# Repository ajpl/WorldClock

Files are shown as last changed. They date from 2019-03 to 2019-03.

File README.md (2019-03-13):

# WorldClock

This is a WorldClock implementation using Atmega 328 and DS1307 as a RTC.

## Inspiration

This project was inspired by [this](https://www.instructables.com/id/The-Wordclock-Grew-Up/) instructable that relies on a DS1302 instead of a DS1307. A couple of changes had to be made since these clocks work in different ways ([DS1302 Datasheet](https://datasheets.maximintegrated.com/en/ds/DS1302.pdf) and [DS1307 Datasheet](https://datasheets.maximintegrated.com/en/ds/DS1307.pdf)).

## How To
- Get all the parts necessary according to the Bill of Materials in Part 8 of the instructable linked above (for electronics you may use the schematic if you prefer)
- Etch the PCB using your favorite method or using a service like [OSH Park](https://oshpark.com)

- Flash the program into your Atmega 328 using your programmer of choice

- Solder every component into your PCB

- Test it out

- Follow the instructions linked above in order to build the clock's enclosure

- Put everything together

- Enjoy!

## Dependencies

- [RTC Lib](https://github.com/adafruit/RTClib)

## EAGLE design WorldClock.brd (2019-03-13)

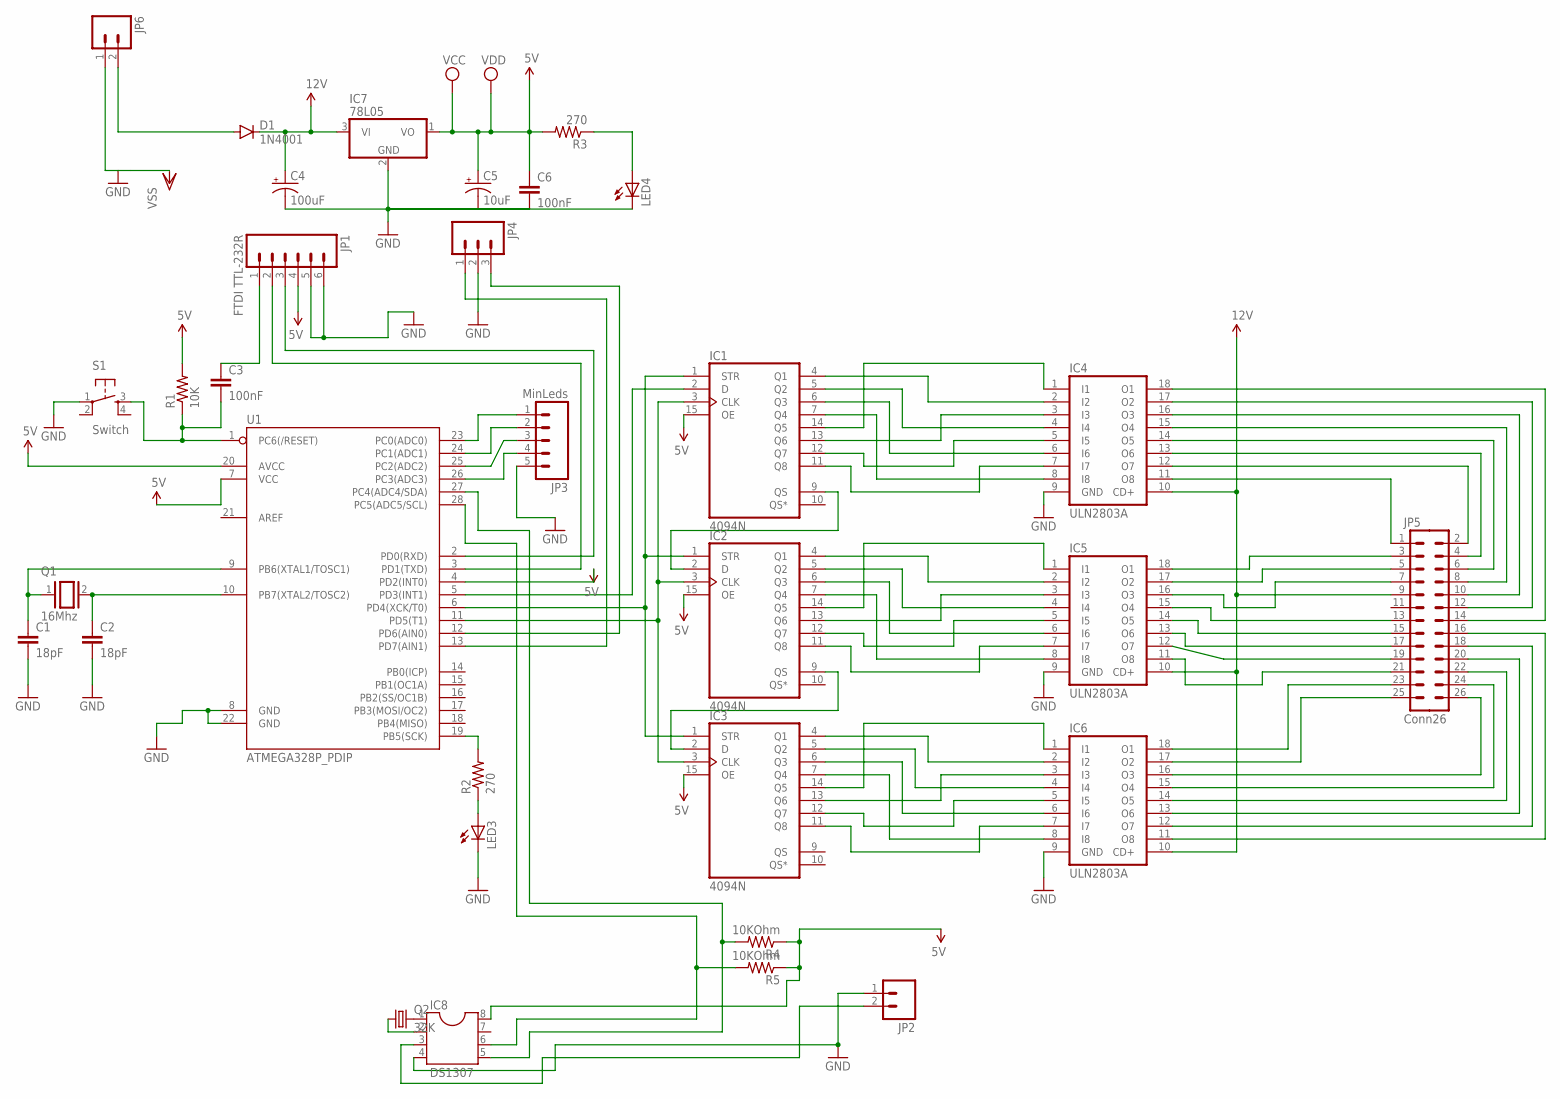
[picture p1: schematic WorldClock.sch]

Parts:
C1, C2: 18pF; CAP-PTH-SMALL2
C3, C6: 100nF; CAP-PTH-SMALL2
C4: 100uF; CPOL-RADIAL-100UF-25V
C5: 10uF; CPOL-RADIAL-10UF-25V
D1: 1N4001; DIODE-1N4148
IC1, IC2, IC3: 4094N; DIL16
IC4, IC5, IC6: ULN2803A; DIL18
IC7: 78L05; TO92
IC8: DS1307; SOCKET-08
JP1: FTDI TTL-232R; 1X06_NO_SILK
JP2, JP6: M025MM; SCREWTERMINAL-5MM-2
JP3: MinLeds; 1X05
JP4: M03-SCREW-5MM; SCREWTERMINAL-5MM-3
JP5: Conn26; 2X13
LED3, LED4: LED5MM
Q1: 16Mhz; QS
Q2: 32K; TC26V
R1: 10K; AXIAL-0.4
R2, R3: 270; AXIAL-0.4
R4, R5: 10KOhm; AXIAL-0.4
S1: Switch; TACTILE-PTH
U1: ATMEGA328P_PDIP; DIL28-3

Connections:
5V: C5.1 (+), C6.1, IC1.15 (OE), IC1.16 (VDD), IC2.15 (OE), IC2.16 (VDD), IC3.15 (OE), IC3.16 (VDD), IC7.1 (VO), IC8.8, JP1.4, R1.P$2 (2), R3.P$2 (2), R4.P$1 (1), R5.P$1 (1), U1.4 (PD2(INT0)), U1.7 (VCC), U1.20 (AVCC)
12V: C4.1 (+), D1.C, IC4.10 (CD+), IC5.10 (CD+), IC6.10 (CD+), IC7.3 (VI), JP5.9
GND: C1.2, C2.2, C4.2 (-), C5.2 (-), C6.2, IC1.8 (VSS), IC2.8 (VSS), IC3.8 (VSS), IC4.9 (GND), IC5.9 (GND), IC6.9 (GND), IC7.2 (GND), IC8.4, JP1.5, JP1.6, JP2.1, JP3.5, JP4.2, JP6.1, LED3.K (C), LED4.K (C), S1.1, U1.8 (GND), U1.22 (GND)
unnamed: C1.1, Q1.1, U1.9 (PB6(XTAL1/TOSC1))
unnamed: C2.1, Q1.2, U1.10 (PB7(XTAL2/TOSC2))
unnamed: C3.2, R1.P$1 (1), S1.3, U1.1 (PC6(/RESET))
unnamed: C3.1, JP1.1
unnamed: JP4.1, U1.13 (PD7(AIN1))
unnamed: JP1.2, U1.3 (PD1(TXD))
unnamed: JP1.3, U1.2 (PD0(RXD))
unnamed: JP4.3, U1.12 (PD6(AIN0))
unnamed: JP3.1, U1.23 (PC0(ADC0))
unnamed: JP3.2, U1.24 (PC1(ADC1))
unnamed: JP3.3, U1.25 (PC2(ADC2))
unnamed: JP3.4, U1.26 (PC3(ADC3))
unnamed: R2.P$2 (2), U1.19 (PB5(SCK))
unnamed: LED3.A, R2.P$1 (1)
unnamed: IC1.4 (Q1), IC4.2 (I2)
unnamed: IC1.5 (Q2), IC4.4 (I4)
unnamed: IC1.6 (Q3), IC4.6 (I6)
unnamed: IC1.7 (Q4), IC4.8 (I8)
unnamed: IC1.14 (Q5), IC4.1 (I1)
unnamed: IC1.13 (Q6), IC4.3 (I3)
unnamed: IC1.12 (Q7), IC4.5 (I5)
unnamed: IC1.11 (Q8), IC4.7 (I7)
unnamed: IC1.9 (QS), IC2.2 (D)
unnamed: IC2.4 (Q1), IC5.2 (I2)
unnamed: IC2.5 (Q2), IC5.4 (I4)
unnamed: IC2.6 (Q3), IC5.6 (I6)
unnamed: IC2.7 (Q4), IC5.8 (I8)
unnamed: IC2.14 (Q5), IC5.1 (I1)
unnamed: IC2.13 (Q6), IC5.3 (I3)
unnamed: IC2.12 (Q7), IC5.5 (I5)
unnamed: IC2.11 (Q8), IC5.7 (I7)
unnamed: IC2.9 (QS), IC3.2 (D)
unnamed: IC3.4 (Q1), IC6.2 (I2)
unnamed: IC3.5 (Q2), IC6.4 (I4)
unnamed: IC3.6 (Q3), IC6.6 (I6)
unnamed: IC3.7 (Q4), IC6.8 (I8)
unnamed: IC3.14 (Q5), IC6.1 (I1)
unnamed: IC3.13 (Q6), IC6.3 (I3)
unnamed: IC3.12 (Q7), IC6.5 (I5)
unnamed: IC3.11 (Q8), IC6.7 (I7)
unnamed: IC1.2 (D), U1.5 (PD3(INT1))
unnamed: IC1.1 (STR), IC2.1 (STR), IC3.1 (STR), U1.6 (PD4(XCK/T0))
unnamed: IC1.3 (CLK), IC2.3 (CLK), IC3.3 (CLK), U1.11 (PD5(T1))
unnamed: IC5.14 (O5), JP5.15
unnamed: LED4.A, R3.P$1 (1)
unnamed: IC5.13 (O6), JP5.17
unnamed: IC4.11 (O8), JP5.1
unnamed: D1.A, JP6.2
unnamed: IC4.12 (O7), JP5.2
unnamed: IC4.13 (O6), JP5.4
unnamed: IC4.14 (O5), JP5.6
unnamed: IC4.15 (O4), JP5.8
unnamed: IC4.16 (O3), JP5.10
unnamed: IC4.17 (O2), JP5.12
unnamed: IC4.18 (O1), JP5.14
unnamed: IC5.18 (O1), JP5.3
unnamed: IC5.17 (O2), JP5.5
unnamed: IC5.16 (O3), JP5.7
unnamed: IC5.15 (O4), JP5.13
unnamed: IC5.12 (O7), JP5.19
unnamed: IC6.18 (O1), JP5.23
unnamed: IC5.11 (O8), JP5.21
unnamed: IC6.17 (O2), JP5.25
unnamed: IC6.16 (O3), JP5.26
unnamed: IC6.15 (O4), JP5.24
unnamed: IC6.14 (O5), JP5.22
unnamed: IC6.13 (O6), JP5.20
unnamed: IC6.12 (O7), JP5.18
unnamed: IC6.11 (O8), JP5.16
unnamed: IC8.6, R5.P$2 (2), U1.28 (PC5(ADC5/SCL))
unnamed: IC8.3, JP2.2
unnamed: IC8.5, R4.P$2 (2), U1.27 (PC4(ADC4/SDA))
unnamed: IC8.1, Q2.2
unnamed: IC8.2, Q2.1

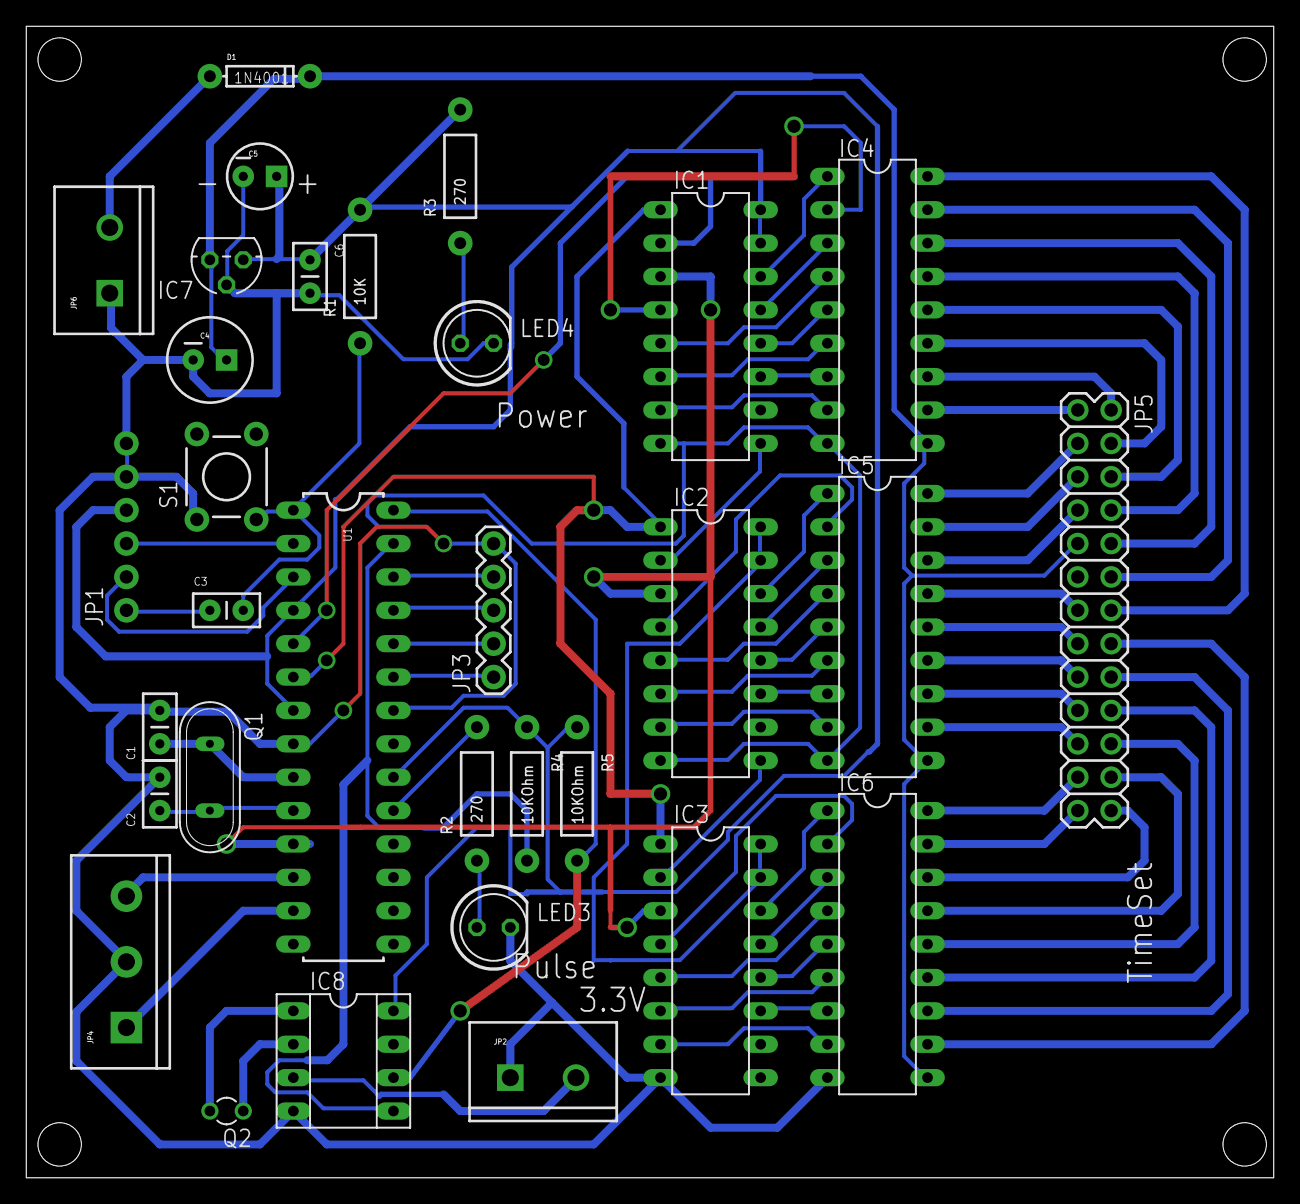
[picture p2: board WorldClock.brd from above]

Board: 2 copper layers, 94.9 x 87.6 mm, 36 parts (0 on the bottom side), 77 nets.

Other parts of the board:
U$1, U$2, U$3, U$4: STAND-OFF

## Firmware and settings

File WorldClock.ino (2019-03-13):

#include <stdio.h>
#include <string.h>
#include <Wire.h>
#include <RTClib.h>

// DAY Brightness setting 0 = off    20 = full
#define DAYBRIGHTNESS 20
// NIGHT Brightness setting 0 = off    20 = full
#define NIGHTBRIGHTNESS 20


// Display output pin assignments
#define MINUTES	Display1=Display1 | (1<<0)
#define MTEN 	Display1=Display1 | (1<<1)
#define HALF	Display1=Display1 | (1<<2)
#define PAST	Display1=Display1 | (1<<3)
#define THREE	Display1=Display1 | (1<<4)
#define ITIS	Display1=Display1 | (1<<5)
#define TWENTY	Display1=Display1 | (1<<6)
#define TO	Display1=Display1 | (1<<7)

#define TWO	Display2=Display2 | (1<<0)
#define SIX	Display2=Display2 | (1<<1)
#define TWELVE	Display2=Display2 | (1<<2)
#define HFIVE	Display2=Display2 | (1<<3)
#define SEVEN	Display2=Display2 | (1<<4)
#define OCLOCK	Display2=Display2 | (1<<5)
#define ONE	Display2=Display2 | (1<<6)
#define QUARTER	Display2=Display2 | (1<<7)

#define EIGHT	Display3=Display3 | (1<<0)
#define MFIVE	Display3=Display3 | (1<<1)
#define ARDUINO	Display3=Display3 | (1<<2)
#define ELEVEN	Display3=Display3 | (1<<3)
#define HTEN	Display3=Display3 | (1<<4)
#define NINE	Display3=Display3 | (1<<5)
#define FOUR	Display3=Display3 | (1<<6)
#define DOUG	Display3=Display3 | (1<<7)

#define LED1    Led1=1
#define LED2    Led2=1
#define LED3    Led3=1
#define LED4    Led4=1



#define INIT_TIMER_COUNT 6
#define RESET_TIMER2 TCNT2 = INIT_TIMER_COUNT




int  hour = 11, minute = 29, second = 00;
static unsigned long msTick = 0; // the number of Millisecond Ticks since we last incremented the second counter
int  count;
int  selftestmode;          // 1 = in self test - flash display
int  DS1307Present = 0;     // flag to indicate that the 1307 is there..    1 = present
char Display1 = 0, Display2 = 0, Display3 = 0, Led1 = 0, Led2 = 0, Led3 = 0, Led4 = 0;
int  OldHardware = 0;  // 1 = we are running on old hardwrae
int  BTNActive = 1;    // the sense of the button inputs (Changes based on hardware type)
int  timercount = 10;  // used for interrupt counting to determine the brightnes of the display

// hardware constants
int LEDClockPin = 5; // Arduino Pin#11 - 4094 Pin 3 clock ERA 11
int LEDDataPin = 3; // Arduino Pin#5  - 4094 pin 2 Data ERA 5
int LEDStrobePin = 4; // Arduino Pin#6  - 4094 pin 1 Strobe ERA 6

// buttons
int FWDButtonPin = 6;
int REVButtonPin = 7;

// Minute LED Pins
int LED1PIN = 14; // Arduino analog 5
int LED2PIN = 15; // Arduino analog 4
int LED3PIN = 16; // Arduino analog 3
int LED4PIN = 17; // Arduino analog 2

int current_brightnes = 0;

/* Create buffers */
char buf[50]; // time output string for debugging


// create an object that talks to the RTC
RTC_DS1307 RTC;
void print_DS1307time()
{
  /* Get the current time and date from the chip */
  //Time t = rtc.time();
  DateTime t = RTC.now();

  /* Format the time and date and insert into the temporary buffer */
  snprintf(buf, sizeof(buf), "DS1307 time: %02d:%02d:%02d",
           t.hour(), t.minute(), t.second());

  /* Print the formatted string to serial so we can see the time */
  Serial.println(buf);

}



void setup()
{
  // initialise the hardware
  // initialize the appropriate pins as outputs:
  pinMode(LEDClockPin, OUTPUT);
  pinMode(LEDDataPin, OUTPUT);
  pinMode(LEDStrobePin, OUTPUT);
  pinMode(FWDButtonPin, INPUT);
  pinMode(REVButtonPin, INPUT);
  pinMode(13, OUTPUT);
  // Minute LEDS
  pinMode(LED1PIN, OUTPUT);
  pinMode(LED2PIN, OUTPUT);
  pinMode(LED3PIN, OUTPUT);
  pinMode(LED4PIN, OUTPUT);

  current_brightnes = DAYBRIGHTNESS;


  Serial.begin(9600);   // setup the serial port to 9600 baud
  SWversion();          // Display the version number of the software
  Wire.begin();
  RTC.begin();
  // test whether the DS1307 is there
  Serial.print("Verifying DS1307 ");
  // start by verifying that the chip has a valid signature RTC.setSqwOutSignal(RTC_DS1307::Frequency_1Hz);
  if (RTC.readByteInRam(0x20) == 0xa5) {
    // Signature is there - set the present flag and mmove on
    DS1307Present = 1;
    Serial.println("present - Valid Signature");
  }
  else
  {
    // Signature isnt there - may be a new chip -
    //   do a write to see if it will hold the signature
    RTC.writeByteInRam(0x20, 0xa5);
    if (RTC.readByteInRam(0x20) == 0xa5) {
      // We can store data - assume that it is a new chip that needs initialisation
      // Start by turning off write protection and clearing the clock halt flag.
      // Make a new time object to set the date and time
      DateTime t(2015, 04, 17, hour, minute, second);
      // Set the time and date on the chip
      RTC.adjust(t);
      // set the DS1307 present flag
      DS1307Present = 1;
      Serial.println("present - new chip initialised.");
    }
    else  Serial.println("absent");
  }

  // determine whether we are running on old or new hardware
  // old hardware tied the push buttons to ground using 4k7 resistors
  // and relied on the buttons to pull them high
  // new hardware uses internal pullups, and uses the buttons
  // to pull the inputs down.

  digitalWrite(FWDButtonPin, HIGH); // Turn on weak pullups
  digitalWrite(REVButtonPin, HIGH); // Turn on weak pullups

  OldHardware = 0;
  if ( digitalRead(FWDButtonPin) == 0 && digitalRead(REVButtonPin) == 0)
  {
    Serial.println("Detected Old Hardware");
    OldHardware = 1; // we have old hardware
    BTNActive = 1; // True = active for old hardware
    digitalWrite(FWDButtonPin, LOW); // Turn off weak pullups
    digitalWrite(REVButtonPin, LOW); // Turn off weak pullups

  }
  else
  {
    Serial.println("Detected New Hardware");
    OldHardware = 0; // we have old hardware
    BTNActive = 0; // True = active for old hardware
  }


  // Initialise Timer2: Timer Prescaler /64,
  TCCR2A = 0;
  TCCR2B |= (1 << CS22);
  TCCR2B &= ~((1 << CS21) | (1 << CS20));
  // Use normal mode
  TCCR2B &= ~((1 << WGM21) | (1 << WGM20));
  // Use internal clock - external clock not used in Arduino
  ASSR |= (0 << AS2);
  //Timer2 Overflow Interrupt Enable
  TIMSK2 |= 1 << TOIE2;
  RESET_TIMER2;
  sei();

  Serial.println("Finished setting up Timer2 Interrupt");


  msTick = millis();    // Initialise the msTick counter

  selftest();  // validate the hardware for the user

  selftestmode = 0;

  if (DS1307Present == 1) {
    // Get the current time and date from the chip
    DateTime t = RTC.now();
    second = t.second();
    minute = t.minute();
    hour = t.hour();
  }

  displaytime();        // display the current time
}


// Interrupt handler - Arduino runs at 16 Mhz, so we have 1000 Overflows per second...
// 1/ ((16000000 / 64) / 256) = 1 / 1000
ISR(TIMER2_OVF_vect) {
  RESET_TIMER2;


  if (timercount-- <= current_brightnes) {
    // Now we write the actual values to the hardware
    shiftOut(LEDDataPin, LEDClockPin, MSBFIRST, Display3);
    shiftOut(LEDDataPin, LEDClockPin, MSBFIRST, Display2);
    shiftOut(LEDDataPin, LEDClockPin, MSBFIRST, Display1);
    digitalWrite(LEDStrobePin, HIGH);
    //delay(2);
    digitalWrite(LEDStrobePin, LOW);
    digitalWrite(LED1PIN, Led1);
    digitalWrite(LED2PIN, Led2);
    digitalWrite(LED3PIN, Led3);
    digitalWrite(LED4PIN, Led4);
  }
  else
  {
    shiftOut(LEDDataPin, LEDClockPin, MSBFIRST, 0);
    shiftOut(LEDDataPin, LEDClockPin, MSBFIRST, 0);
    shiftOut(LEDDataPin, LEDClockPin, MSBFIRST, 0);
    digitalWrite(LEDStrobePin, HIGH);
    //delay(2);
    digitalWrite(LEDStrobePin, LOW);
    digitalWrite(LED1PIN, 0);
    digitalWrite(LED2PIN, 0);
    digitalWrite(LED3PIN, 0);
    digitalWrite(LED4PIN, 0);

  }
  if (timercount == 0) timercount = 20;



}



void ledsoff(void) {
  Display1 = 0;
  Display2 = 0;
  Display3 = 0;
  Led1 = 0;
  Led2 = 0;
  Led3 = 0;
  Led4 = 0;
}



void selftest(void) {
  // start by clearing the display to a known state
  ledsoff();
  ITIS;
  delay(500);
  ledsoff();
  MTEN;
  delay(500);
  ledsoff();
  HALF;
  delay(500);
  ledsoff();
  TWENTY;
  delay(500);
  ledsoff();
  QUARTER;
  delay(500);
  ledsoff();
  MFIVE;
  delay(500);
  ledsoff();
  MINUTES;
  delay(500);
  ledsoff();
  PAST;
  delay(500);
  ledsoff();
  TO;
  delay(500);
  ledsoff();
  ONE;
  delay(500);
  ledsoff();
  TWO;
  delay(500);
  ledsoff();
  THREE;
  delay(500);
  ledsoff();
  FOUR;
  delay(500);
  ledsoff();
  HFIVE;
  delay(500);
  ledsoff();
  SIX;
  delay(500);
  ledsoff();
  SEVEN;
  delay(500);
  ledsoff();
  EIGHT;
  delay(500);
  ledsoff();
  NINE;
  delay(500);
  ledsoff();
  HTEN;
  delay(500);
  ledsoff();
  ELEVEN;
  delay(500);
  ledsoff();
  TWELVE;
  delay(500);
  ledsoff();
  OCLOCK;
  delay(500);
  ledsoff();
  DOUG;
  delay(500);
  ledsoff();
  ARDUINO;
  delay(500);
  ledsoff();
  LED1;
  delay(500);
  ledsoff();
  LED2;
  delay(500);
  ledsoff();
  LED3;
  delay(500);
  ledsoff();
  LED4;
  delay(500);

  for (int i = 0; i < 5; i++)
  {
    Display1 = 255;
    Display2 = 255;
    Display3 = 255;
    delay(500);
    ledsoff();
    delay(500);
  }

}


void displaytime(void) {

  // start by clearing the display to a known state
  ledsoff();

  // Now, turn on the "It is" leds
  ITIS;
  Serial.print("It is ");

  // now we display the appropriate minute counter
  if ((minute > 4) && (minute < 10)) {
    MFIVE;
    MINUTES;
    Serial.print("Five Minutes ");
  }
  if ((minute > 9) && (minute < 15)) {
    MTEN;
    MINUTES;
    Serial.print("Ten Minutes ");
  }
  if ((minute > 14) && (minute < 20)) {
    QUARTER;
    Serial.print("Quarter ");
  }
  if ((minute > 19) && (minute < 25)) {
    TWENTY;
    MINUTES;
    Serial.print("Twenty Minutes ");
  }
  if ((minute > 24) && (minute < 30)) {
    TWENTY;
    MFIVE;
    MINUTES;
    Serial.print("Twenty Five Minutes ");
  }
  if ((minute > 29) && (minute < 35)) {
    HALF;
    Serial.print("Half ");
  }
  if ((minute > 34) && (minute < 40)) {
    TWENTY;
    MFIVE;
    MINUTES;
    Serial.print("Twenty Five Minutes ");
  }
  if ((minute > 39) && (minute < 45)) {
    TWENTY;
    MINUTES;
    Serial.print("Twenty Minutes ");
  }
  if ((minute > 44) && (minute < 50)) {
    QUARTER;
    Serial.print("Quarter ");
  }
  if ((minute > 49) && (minute < 55)) {
    MTEN;
    MINUTES;
    Serial.print("Ten Minutes ");
  }
  if (minute > 54) {
    MFIVE;
    MINUTES;
    Serial.print("Five Minutes ");
  }



  if ((minute < 5))
  {
    switch (hour) {
      case 1:
      case 13:
        ONE;
        Serial.print("One ");
        break;
      case 2:
      case 14:
        TWO;
        Serial.print("Two ");
        break;
      case 3:
      case 15:
        THREE;
        Serial.print("Three ");
        break;
      case 4:
      case 16:
        FOUR;
        Serial.print("Four ");
        break;
      case 5:
      case 17:
        HFIVE;
        Serial.print("Five ");
        break;
      case 6:
      case 18:
        SIX;
        Serial.print("Six ");
        break;
      case 7:
      case 19:
        SEVEN;
        Serial.print("Seven ");
        break;
      case 8:
      case 20:
        EIGHT;
        Serial.print("Eight ");
        break;
      case 9:
      case 21:
        NINE;
        Serial.print("Nine ");
        break;
      case 10:
      case 22:
        HTEN;
        Serial.print("Ten ");
        break;
      case 11:
      case 23:
        ELEVEN;
        Serial.print("Eleven ");
        break;
      case 0:
      case 12:
        TWELVE;
        Serial.print("Twelve ");
        break;
    }
    OCLOCK;
    Serial.println("O'Clock");
  }
  else if ((minute < 35) && (minute > 4))
  {
    PAST;
    Serial.print("Past ");
    switch (hour) {
      case 1:
      case 13:
        ONE;
        Serial.println("One ");
        break;
      case 2:
      case 14:
        TWO;
        Serial.println("Two ");
        break;
      case 3:
      case 15:
        THREE;
        Serial.println("Three ");
        break;
      case 4:
      case 16:
        FOUR;
        Serial.println("Four ");
        break;
      case 5:
      case 17:
        HFIVE;
        Serial.println("Five ");
        break;
      case 6:
      case 18:
        SIX;
        Serial.println("Six ");
        break;
      case 7:
      case 19:
        SEVEN;
        Serial.println("Seven ");
        break;
      case 8:
      case 20:
        EIGHT;
        Serial.println("Eight ");
        break;
      case 9:
      case 21:
        NINE;
        Serial.println("Nine ");
        break;
      case 10:
      case 22:
        HTEN;
        Serial.println("Ten ");
        break;
      case 11:
      case 23:
        ELEVEN;
        Serial.println("Eleven ");
        break;
      case 0:
      case 12:
        TWELVE;
        Serial.println("Twelve ");
        break;
    }
  }
  else
  {
    // if we are greater than 34 minutes past the hour then display
    // the next hour, as we will be displaying a 'to' sign
    TO;
    Serial.print("To ");
    switch (hour) {
      case 1:
      case 13:
        TWO;
        Serial.println("Two ");
        break;
      case 14:
      case 2:
        THREE;
        Serial.println("Three ");
        break;
      case 15:
      case 3:
        FOUR;
        Serial.println("Four ");
        break;
      case 4:
      case 16:
        HFIVE;
        Serial.println("Five ");
        break;
      case 5:
      case 17:
        SIX;
        Serial.println("Six ");
        break;
      case 6:
      case 18:
        SEVEN;
        Serial.println("Seven ");
        break;
      case 7:
      case 19:
        EIGHT;
        Serial.println("Eight ");
        break;
      case 8:
      case 20:
        NINE;
        Serial.println("Nine ");
        break;
      case 9:
      case 21:
        HTEN;
        Serial.println("Ten ");
        break;
      case 10:
      case 22:
        ELEVEN;
        Serial.println("Eleven ");
        break;
      case 11:
      case 23:
        TWELVE;
        Serial.println("Twelve ");
        break;
      case 0:
      case 12:
        ONE;
        Serial.println("One ");
        break;
    }
  }



  // now we can illuminate the extra minute LEDs

  if ((minute - (minute / 5) * 5) == 1) {
    LED1;
  }
  if ((minute - (minute / 5) * 5) == 2) {
    LED1;
    LED2;
  }
  if ((minute - (minute / 5) * 5) == 3) {
    LED1;
    LED2;
    LED3;
  }
  if ((minute - (minute / 5) * 5) == 4) {
    LED1;
    LED2;
    LED3;
    LED4;
  }


}


void incrementtime(void) {
  // increment the time counters keeping care to rollover as required
  second = 0;
  if (++minute >= 60) {
    minute = 0;
    if (++hour == 25) {
      hour = 1;
    }
  }
  // debug outputs
  Serial.println();
  if (DS1307Present == 1) print_DS1307time();
  else Serial.print("Arduino Time: " );
  Serial.print(hour);
  Serial.print(":");
  Serial.print(minute);
  Serial.print(":");
  Serial.println(second);

}


void SWversion(void) {
  delay(2000);
  Serial.println();
  Serial.println("Wordclock -Arduino v3.0a - reduced brightnes version");
  Serial.println("(c)2009,2010 Doug Jackson");
}


void loop(void)
{
  int previous_minute;

  if (DS1307Present == 1)
    previous_minute = minute;  // keep track of the last minute read to spot faulty DS1307 chips

  //Serial.println("Loop Started");

  // heart of the timer - keep looking at the millisecond timer on the Arduino
  // and increment the seconds counter every 1000 ms
  if ( millis() - msTick > 999) {
    msTick = millis();
    second++;
    // Flash the onboard Pin13 Led so we know something is hapening!
    digitalWrite(13, HIGH);
    delay(50);
    digitalWrite(13, LOW);
    delay(50);
    digitalWrite(13, HIGH);
    delay(50);
    digitalWrite(13, LOW);

    if (second % 5 == 0) {
      Serial.print(second);
      Serial.print("..");
    }
  }



  //test to see if we need to increment the time counters
  if (second == 60)
  {
    incrementtime();
    displaytime();
  }

  if (DS1307Present == 1) {
    // Get the current time and date from the chip
    DateTime t = RTC.now();
    second = t.second();
    minute = t.minute();
    hour = t.hour();

  }

  // set the brightnes level based on the current hour - night=7pm - 6.59am
  //
  if ((hour < 7) | (hour >= 19))
    current_brightnes = NIGHTBRIGHTNESS;
  else
    current_brightnes = DAYBRIGHTNESS;


  // test to see if both buttons are being held down
  // if so  - start a self test till both buttons are held
  // down again.
  if ( digitalRead(FWDButtonPin) == BTNActive && digitalRead(REVButtonPin) == BTNActive)
  {
    selftestmode = !selftestmode;
    if (selftestmode) Serial.println("Selftest Mode TRUE");
    else Serial.println("Selftest mode FALSE");
  }

  //    if (selftestmode) {
  //      for(int i=0; i<100; i++)
  //      {
  //      Display1=255; Display2=255; Display3=255;
  //      WriteLEDs(); delay(101-i);
  //      ledsoff(); WriteLEDs();delay(101-i);
  //      if (digitalRead(FWDButtonPin)==1) selftestmode=!selftestmode;
  //
  //      }
  //      displaytime();
  //
  //    }


  // test to see if a forward button is being held down
  // for time setting
  if (digitalRead(FWDButtonPin) == BTNActive )
    // the forward button is down
    // and it has been more than one second since we
    // last looked

  {
    Serial.println("Forward Button Down");
    //minute=(((minute/5)*5) +5);
    incrementtime();
    second++;  // Increment the second counter to ensure that the name
    // flash doesnt happen when setting time
    if (DS1307Present == 1) {
      // Make a new time object to set the date and time
      DateTime t(2015, 04, 17, hour, minute, second);
      // Set the time and date on the chip
      RTC.adjust(t);
    }
    delay(100);
    displaytime();
  }

  // test to see if the back button is being held down
  // for time setting
  if (digitalRead(REVButtonPin) == BTNActive )
  {

    Serial.println("Backwards Button Down");
    minute--;
    minute--;
    second = 0; // decrement the minute counter
    if (minute < 0) {
      minute = 58;
      if (--hour < 0) hour = 23;
    }
    incrementtime();
    second++;  // Increment the second counter to ensure that the name
    // flash doesnt happen when setting time


    if (DS1307Present == 1) {
      // Make a new time object to set the date and time
      DateTime t(2015, 04, 17, hour, minute, second);
      // Set the time and date on the chip
      RTC.adjust(t);
    }

    displaytime();
    delay(100);
  }

}

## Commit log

2019-03-13 Arduino program
2019-03-13 PCB design and schematics
    [WorldClock.brd, WorldClock.sch]

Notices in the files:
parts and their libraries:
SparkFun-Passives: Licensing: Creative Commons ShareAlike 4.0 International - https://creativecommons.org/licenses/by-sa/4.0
